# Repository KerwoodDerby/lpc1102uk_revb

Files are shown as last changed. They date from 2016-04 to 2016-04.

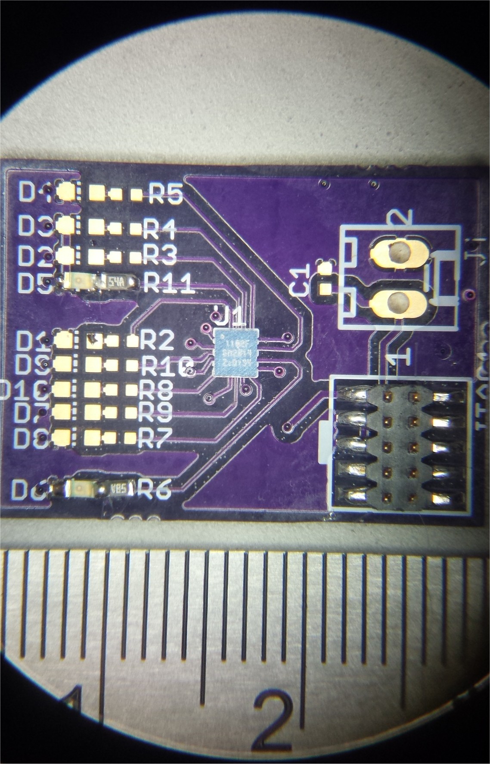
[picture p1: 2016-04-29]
lpc1102uk_revb.jpg

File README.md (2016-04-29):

# lpc1102uk_revb

## A slight improvement on richardeoin's OSHPark design.
That design can be found [here](https://oshpark.com/shared_projects/Tokc44bz).

##My revision

I wanted access to the interior pins, so I tweaked the WLCSP16 pattern to give me a little room
for a 5 mil trace. This exceeds the design rules for OSHPark 2-layer boards, but I can claim
success, having just gotten my [boards](https://oshpark.com/shared_projects/Yf2WkhM2) back and
successfully programmed my diminutive LPC1102UK!

Only the XTALIN pin is not brought out, since I thought that wasn't critical for doing
exploratory programming. I made other changes, mostly the size of the other LEDs and resistors.

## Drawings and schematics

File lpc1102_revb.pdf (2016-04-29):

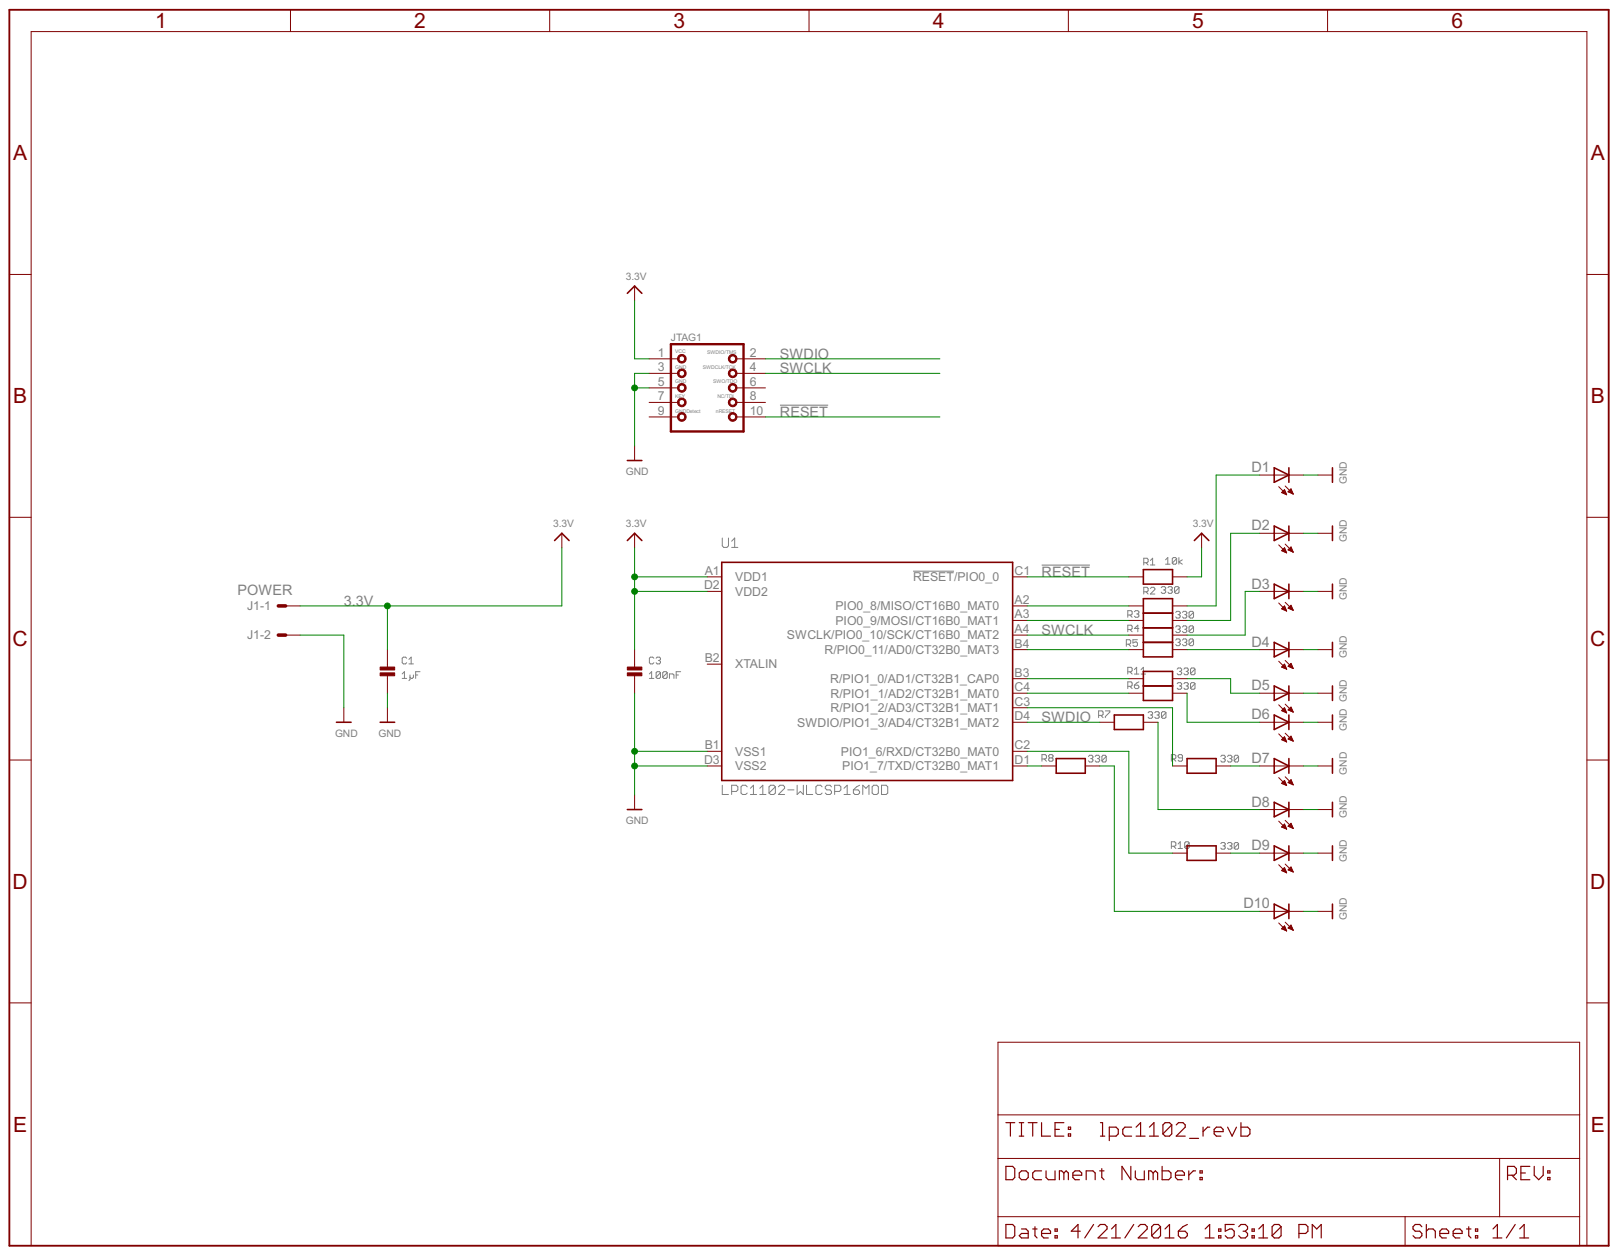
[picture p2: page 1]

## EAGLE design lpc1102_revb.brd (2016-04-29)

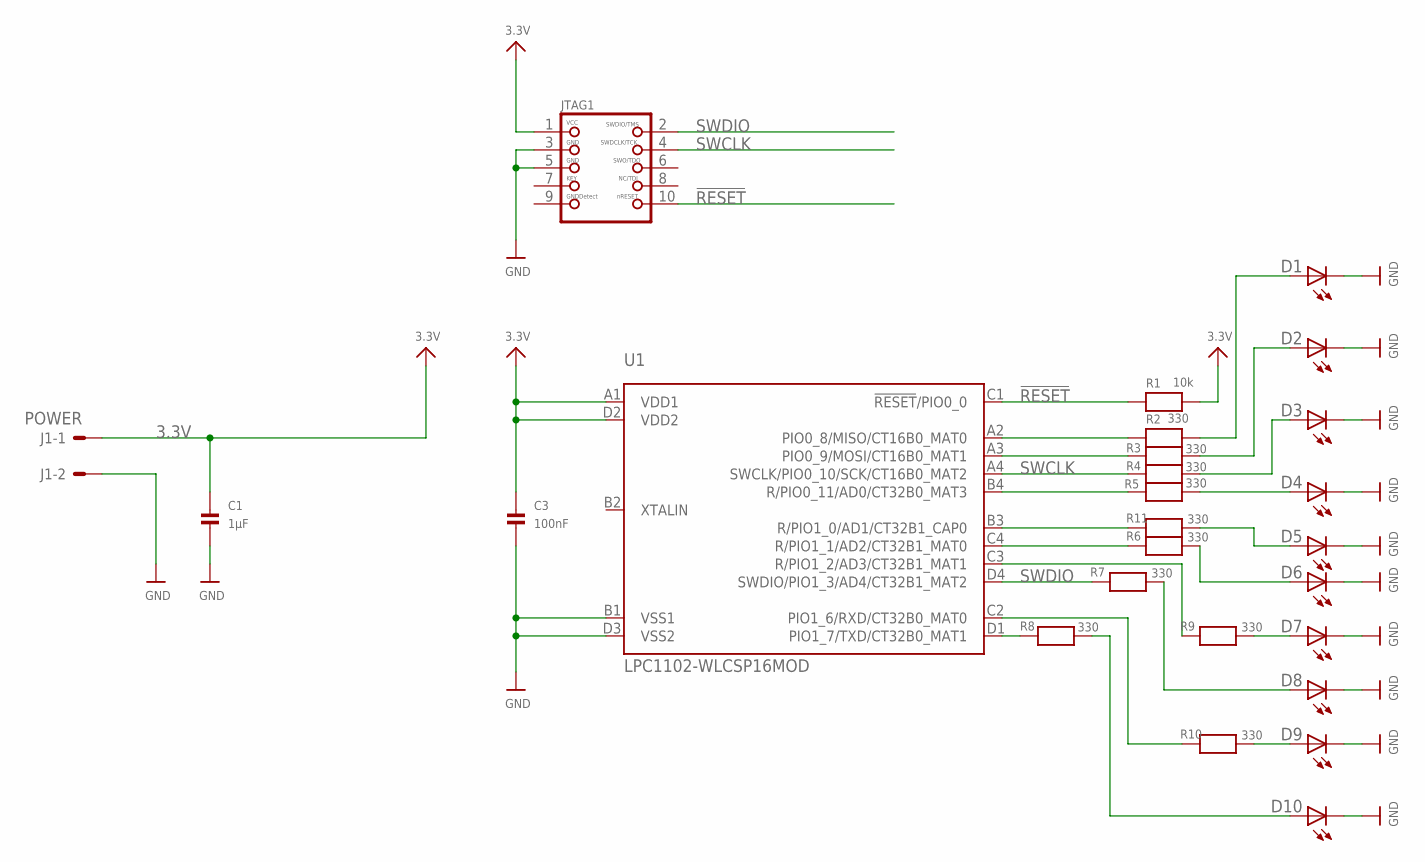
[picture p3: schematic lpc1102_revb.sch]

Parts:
C1: 1µF; _0402
C3: 100nF; _0402
D1, D2, D3, D4, D5, D6, D7, D8, D9, D10: LEDCHIP-LED0603; CHIP-LED0603
J1: POWER; 6410-02
JTAG1: JTAG-CORTEXM3SMT; 2X05_1.27MM_SMT
R1: 10k; _0402
R2, R3, R4, R5, R6, R7, R8, R9, R10, R11: 330; _0402
U1: LPC1102-WLCSP16MOD; WLCSP16_MOD

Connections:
3.3V: C1.1, C3.1, J1.1, JTAG1.1, R1.2, U1.A1 (VDD1), U1.D2 (VDD2)
!RESET: JTAG1.10, R1.1, U1.C1 (!RESET!/PIO0_0)
GND: C1.2, C3.2, D1.C, D2.C, D3.C, D4.C, D5.C, D6.C, D7.C, D8.C, D9.C, D10.C, J1.2, JTAG1.3, JTAG1.5, U1.B1 (VSS1), U1.D3 (VSS2)
unnamed: R8.1, U1.D1 (PIO1_7/TXD/CT32B0_MAT1)
unnamed: D1.A, R2.2
unnamed: R6.1, U1.C4 (R/PIO1_1/AD2/CT32B1_MAT0)
unnamed: R5.1, U1.B4 (R/PIO0_11/AD0/CT32B0_MAT3)
unnamed: D5.A, R11.2
unnamed: R3.1, U1.A3 (PIO0_9/MOSI/CT16B0_MAT1)
unnamed: R2.1, U1.A2 (PIO0_8/MISO/CT16B0_MAT0)
unnamed: R9.1, U1.C3 (R/PIO1_2/AD3/CT32B1_MAT1)
unnamed: D7.A, R9.2
unnamed: R10.1, U1.C2 (PIO1_6/RXD/CT32B0_MAT0)
unnamed: D9.A, R10.2
unnamed: R11.1, U1.B3 (R/PIO1_0/AD1/CT32B1_CAP0)
unnamed: D2.A, R3.2
unnamed: D3.A, R4.2
unnamed: D4.A, R5.2
unnamed: D6.A, R6.2
unnamed: D8.A, R7.2
unnamed: D10.A, R8.2
SWCLK: JTAG1.4, R4.1, U1.A4 (SWCLK/PIO0_10/SCK/CT16B0_MAT2)
SWDIO: JTAG1.2, R7.1, U1.D4 (SWDIO/PIO1_3/AD4/CT32B1_MAT2)

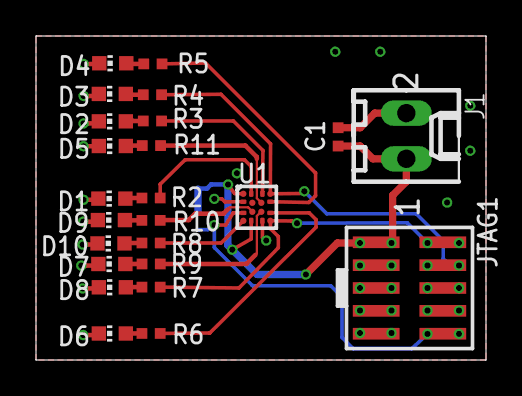
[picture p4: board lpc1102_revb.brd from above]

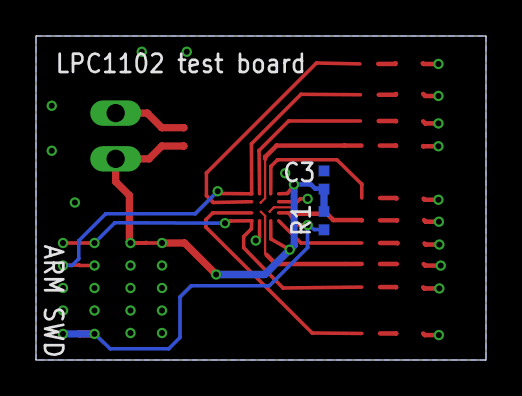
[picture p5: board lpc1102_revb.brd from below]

Board: 2 copper layers, 25.0 x 18.0 mm, 26 parts (2 on the bottom side), 23 nets.

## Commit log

2016-04-29 Added files via upload
    Initial commit
    [lpc1102_revb.brd, lpc1102_revb.sch]
2016-04-29 Added a photo of the working board

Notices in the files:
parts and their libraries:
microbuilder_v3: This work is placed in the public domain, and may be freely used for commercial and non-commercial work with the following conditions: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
